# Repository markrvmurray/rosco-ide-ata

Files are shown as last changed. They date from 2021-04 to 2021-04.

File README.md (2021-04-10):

# IDE/ATA Interface for Rosco_68k

**(c) 2021 Mark R V Murray**

_v1.1 - first public release_

This is a minimalist PIO-only interface to PATA hard disk and
compatible devices.

It has received minimal testing, and is being released in the hope
that it may be useful to someone, somewhere.

The materials in this repository will, when assembled, give a board
that will map the IDE registers into the Rosco_68k's address space.

The addresses are mapped as follows:

| Address | Read | Write | Width in bits |
--- | --- | --- | ---
| 00F80040 | DATA | DATA | 16 |
| 00F80042 | Error | Features | 8 |
| 00F80044 | Sector Count | Sector Count | 8 |
| 00F80046 | Sector Number | Sector Number | 8 |
| 00F80048 | Cylinder Low | Cyllinder Low | 8 |
| 00F8004A | Cylinder High | Cylinder High | 8 |
| 00F8004C | Device and Head | Device and Head | 8 |
| 00F8004E | Status | Command | 8 |
| 00F80050 | (Not used) | | |
| 00F80052 | (Not used) | | |
| 00F80054 | (Not used) | | |
| 00F80056 | (Not used) | | |
| 00F80058 | (Not used) | | |
| 00F8005A | (Not used) | | |
| 00F8005C | Alternate Status | Device Control | 8 |
| 00F8005E | (Not used) | | |

The above memory locations base address may be changed by changing
the U1 image.  This is written in CUPL, and you will need a programmer
capable of programming GAL16V8s or the equivalent.

The supplied GAL images and jumper setting defaults will give the
IDE device IPL3. To change this, the three IPL jumpers on the board
will need to be changed; IPL0 and IPL1 can be cut, and all three
can be (re-)bridged with a solder blob if necessary.

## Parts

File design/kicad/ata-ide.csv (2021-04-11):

Ref | Value | Footprint | Datasheet | Manufacturer | Vendor
C1 | 100n | Capacitors_THT:C_Rect_L4.0mm_W2.5mm_P2.50mm | ~
C2 | 100n | Capacitors_THT:C_Rect_L4.0mm_W2.5mm_P2.50mm | ~
C3 | 100n | Capacitors_THT:C_Rect_L4.0mm_W2.5mm_P2.50mm | ~
C4 | 100n | Capacitors_THT:C_Rect_L4.0mm_W2.5mm_P2.50mm | ~
C5 | 100n | Capacitors_THT:C_Rect_L4.0mm_W2.5mm_P2.50mm | ~
C6 | 1u | Capacitors_THT:C_Rect_L7.0mm_W4.5mm_P5.00mm | ~
C7 | 10u | Capacitors_THT:CP_Radial_D8.0mm_P2.50mm | ~
C8 | 100u | Capacitors_THT:CP_Radial_D8.0mm_P2.50mm | ~
C9 | 4u7 | Capacitors_THT:C_Rect_L7.0mm_W4.5mm_P5.00mm | ~
D1 | LED | LEDs:LED_D5.0mm | http://www.farnell.com/datasheets/1811043.pdf |  | uk.farnell.com 2314284
J1 | Conn_02x32_Odd_Even | Connector_PinHeader_2.54mm:PinHeader_2x32_P2.54mm_Vertical | https://www.we-online.de/katalog/datasheet/613064243121.pdf |  | uk.farnell.com 2984322
J2 | Conn_02x20_Odd_Even | Pin_Headers:Pin_Header_Straight_2x20_Pitch2.54mm | http://www.farnell.com/datasheets/2012759.pdf |  | uk.farnell.com 1106737
J3 | Conn_02x22_Odd_Even | Pin_Headers:Pin_Header_Straight_2x22_Pitch2.00mm | http://www.farnell.com/datasheets/2701933.pdf |  | uk.farnell.com 1756945
JP1 | Pin 20 5V Supply | Pin_Headers:Pin_Header_Straight_1x02_Pitch2.54mm | ~
JP2 | SolderJumper_2_Bridged | Jumper:SolderJumper-2_P1.3mm_Bridged_Pad1.0x1.5mm | ~
JP3 | SolderJumper_2_Bridged | Jumper:SolderJumper-2_P1.3mm_Bridged_Pad1.0x1.5mm | ~
JP4 | SolderJumper_2_Bridged | Jumper:SolderJumper-2_P1.3mm_Bridged_Pad1.0x1.5mm | ~
JP5 | SolderJumper_2_Open | Jumper:SolderJumper-2_P1.3mm_Open_Pad1.0x1.5mm | ~
Q1 | 2N2907 | Package_TO_SOT_THT:TO-18-3 | http://www.farnell.com/datasheets/2869790.pdf |  | uk.farnell.com 9206892
R1 | 10k | Resistors_THT:R_Axial_DIN0207_L6.3mm_D2.5mm_P10.16mm_Horizontal | ~
R2 | 4k7 | Resistors_THT:R_Axial_DIN0207_L6.3mm_D2.5mm_P10.16mm_Horizontal | ~
R3 | 10k | Resistors_THT:R_Axial_DIN0207_L6.3mm_D2.5mm_P10.16mm_Horizontal | ~
R4 | 330 | Resistors_THT:R_Axial_DIN0207_L6.3mm_D2.5mm_P10.16mm_Horizontal | ~
R5 | 10k | Resistors_THT:R_Axial_DIN0207_L6.3mm_D2.5mm_P10.16mm_Horizontal | ~
U1 | 16V8 | Housings_DIP:DIP-20_W7.62mm_Socket_LongPads | http://www.farnell.com/datasheets/30132.pdf |  | uk.farnell.com 1551768
U2 | ATF750 | Housings_DIP:DIP-24_W7.62mm_Socket_LongPads | http://www.farnell.com/datasheets/1627044.pdf |  | uk.farnell.com 3580674
U3 | 74HCT241 | Housings_DIP:DIP-20_W7.62mm_Socket_LongPads | http://www.ti.com/lit/ds/symlink/sn74ls241.pdf |  | uk.farnell.com 3006090
U4 | 74HCT245 | Housings_DIP:DIP-20_W7.62mm_Socket_LongPads | http://www.ti.com/lit/gpn/sn74HC245 |  | uk.farnell.com 3119519
U5 | 74HCT245 | Housings_DIP:DIP-20_W7.62mm_Socket_LongPads | http://www.ti.com/lit/gpn/sn74HC245 |  | uk.farnell.com 3119519

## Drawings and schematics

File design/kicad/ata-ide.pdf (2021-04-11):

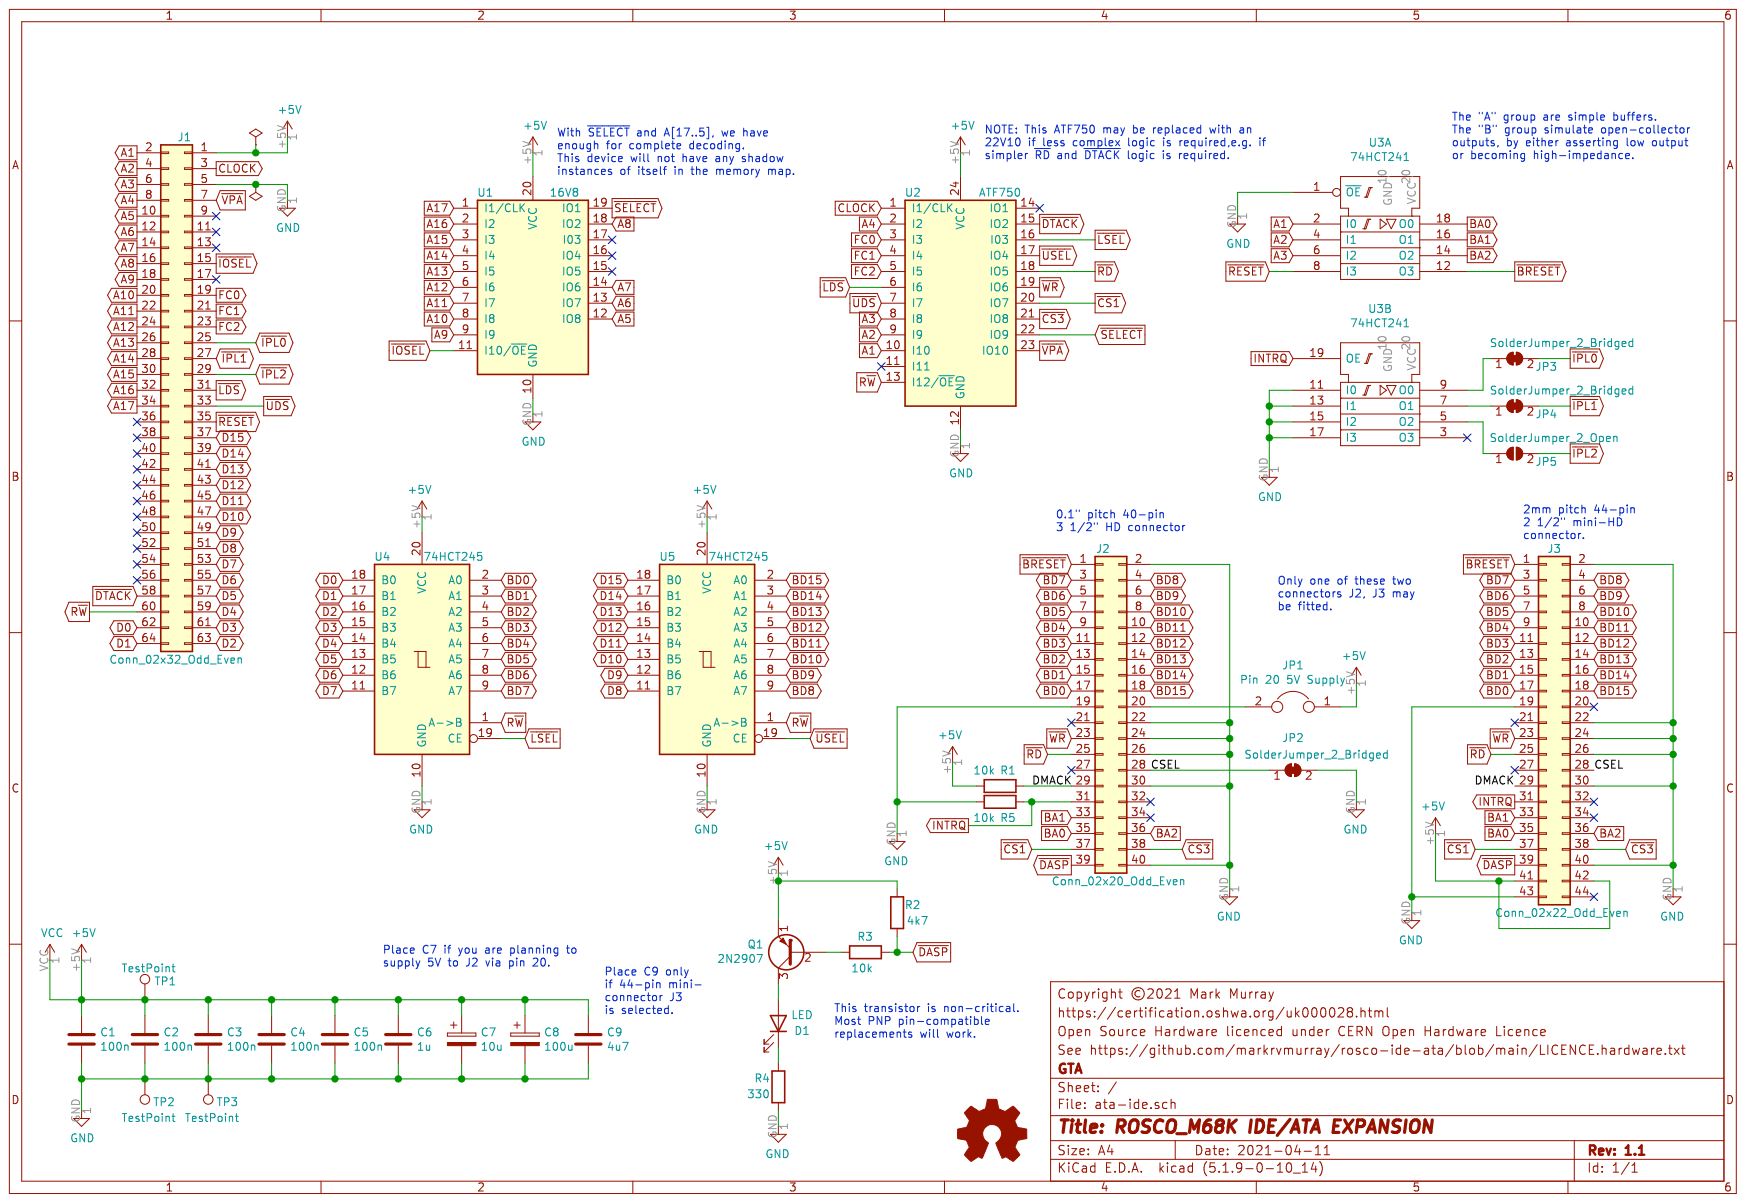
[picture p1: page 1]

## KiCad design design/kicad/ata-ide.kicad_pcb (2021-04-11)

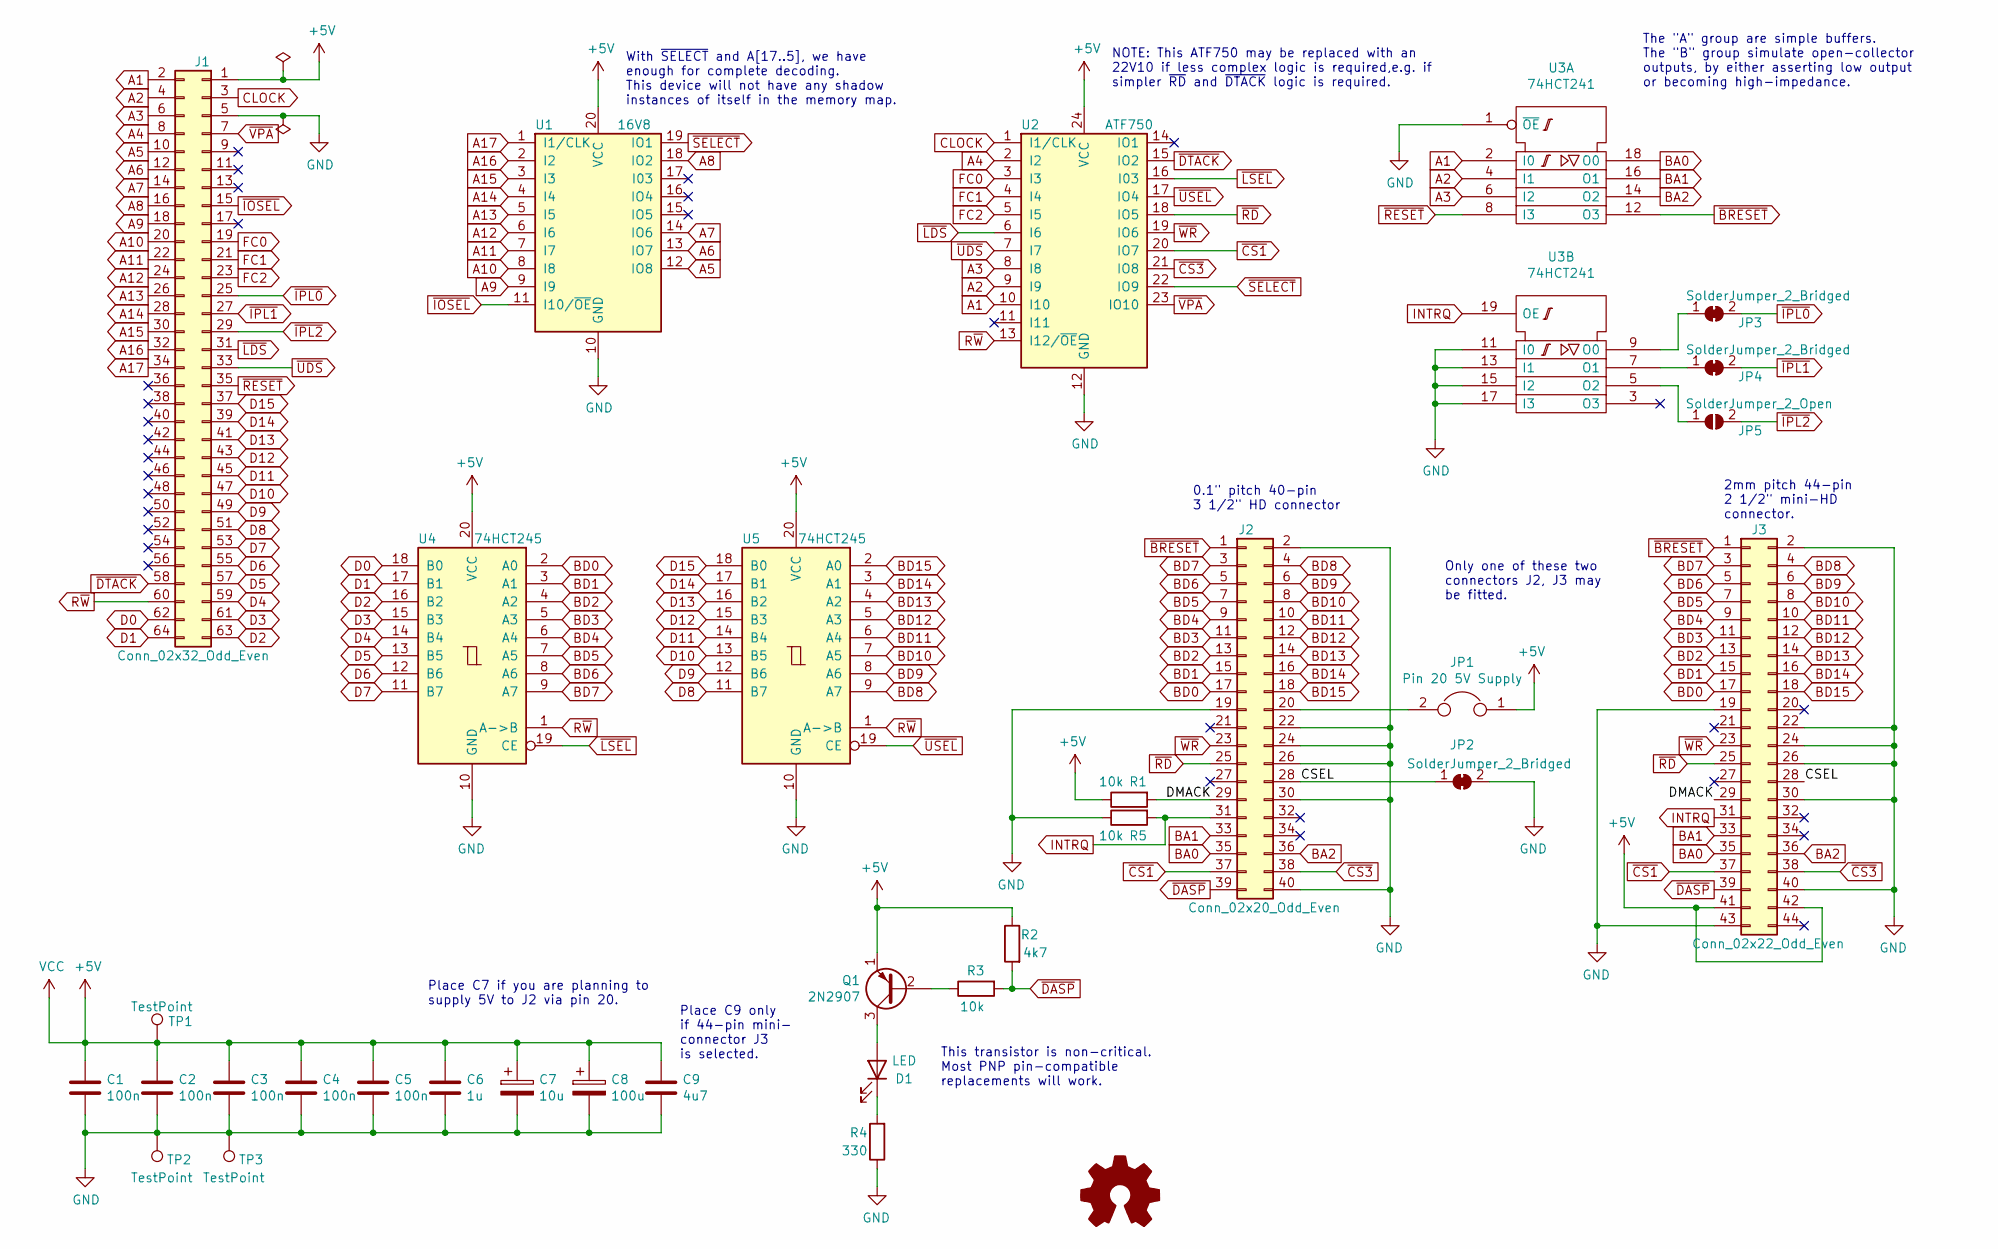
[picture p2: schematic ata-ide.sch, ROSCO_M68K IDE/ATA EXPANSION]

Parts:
C1, C2, C3, C4, C5: 100n; C_Rect_L4.0mm_W2.5mm_P2.50mm
C6: 1u; C_Rect_L7.0mm_W4.5mm_P5.00mm
C7: 10u; CP_Radial_D8.0mm_P2.50mm
C8: 100u; CP_Radial_D8.0mm_P2.50mm
C9: 4u7; C_Rect_L7.0mm_W4.5mm_P5.00mm
D1: LED; LED_D5.0mm
J1: Conn_02x32_Odd_Even; PinHeader_2x32_P2.54mm_Vertical
J2: Conn_02x20_Odd_Even; Pin_Header_Straight_2x20_Pitch2.54mm
J3: Conn_02x22_Odd_Even; Pin_Header_Straight_2x22_Pitch2.00mm
JP1: Pin 20 5V Supply; Pin_Header_Straight_1x02_Pitch2.54mm
JP2, JP3, JP4: SolderJumper_2_Bridged; SolderJumper-2_P1.3mm_Bridged_Pad1.0x1.5mm
JP5: SolderJumper_2_Open; SolderJumper-2_P1.3mm_Open_Pad1.0x1.5mm
Q1: 2N2907; TO-18-3
R1, R3, R5: 10k; R_Axial_DIN0207_L6.3mm_D2.5mm_P10.16mm_Horizontal
R2: 4k7; R_Axial_DIN0207_L6.3mm_D2.5mm_P10.16mm_Horizontal
R4: 330; R_Axial_DIN0207_L6.3mm_D2.5mm_P10.16mm_Horizontal
TP1, TP2, TP3: TestPoint; Measurement_Point_Round-TH_Big
U1: 16V8; DIP-20_W7.62mm_Socket_LongPads
U2: ATF750; DIP-24_W7.62mm_Socket_LongPads
U3: 74HCT241; DIP-20_W7.62mm_Socket_LongPads
U4, U5: 74HCT245; DIP-20_W7.62mm_Socket_LongPads

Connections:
/CSEL: J2.28, J3.28, JP2.1 (A)
/DMACK: J2.29, J3.29, R1.2
A1: J1.2, U2.10 (I10), U3.2 (I0)
A2: J1.4, U2.9 (I9), U3.4 (I1)
A3: J1.6, U2.8 (I8), U3.6 (I2)
A4: J1.8, U2.2 (I2)
A5: J1.10, U1.12 (IO8)
A6: J1.12, U1.13 (IO7)
A7: J1.14, U1.14 (IO6)
A8: J1.16, U1.18 (IO2)
A9: J1.18, U1.9 (I9)
A10: J1.20, U1.8 (I8)
A11: J1.22, U1.7 (I7)
A12: J1.24, U1.6 (I6)
A13: J1.26, U1.5 (I5)
A14: J1.28, U1.4 (I4)
A15: J1.30, U1.3 (I3)
A16: J1.32, U1.2 (I2)
A17: J1.34, U1.1 (I1/CLK)
BA0: J2.35, J3.35, U3.18 (O0)
BA1: J2.33, J3.33, U3.16 (O1)
BA2: J2.36, J3.36, U3.14 (O2)
BD0: J2.17, J3.17, U4.2 (A0)
BD1: J2.15, J3.15, U4.3 (A1)
BD2: J2.13, J3.13, U4.4 (A2)
BD3: J2.11, J3.11, U4.5 (A3)
BD4: J2.9, J3.9, U4.6 (A4)
BD5: J2.7, J3.7, U4.7 (A5)
BD6: J2.5, J3.5, U4.8 (A6)
BD7: J2.3, J3.3, U4.9 (A7)
BD8: J2.4, J3.4, U5.9 (A7)
BD9: J2.6, J3.6, U5.8 (A6)
BD10: J2.8, J3.8, U5.7 (A5)
BD11: J2.10, J3.10, U5.6 (A4)
BD12: J2.12, J3.12, U5.5 (A3)
BD13: J2.14, J3.14, U5.4 (A2)
BD14: J2.16, J3.16, U5.3 (A1)
BD15: J2.18, J3.18, U5.2 (A0)
CLOCK: J1.3, U2.1 (I1/CLK)
D0: J1.62, U4.18 (B0)
D1: J1.64, U4.17 (B1)
D2: J1.63, U4.16 (B2)
D3: J1.61, U4.15 (B3)
D4: J1.59, U4.14 (B4)
D5: J1.57, U4.13 (B5)
D6: J1.55, U4.12 (B6)
D7: J1.53, U4.11 (B7)
D8: J1.51, U5.11 (B7)
D9: J1.49, U5.12 (B6)
D10: J1.47, U5.13 (B5)
D11: J1.45, U5.14 (B4)
D12: J1.43, U5.15 (B3)
D13: J1.41, U5.16 (B2)
D14: J1.39, U5.17 (B1)
D15: J1.37, U5.18 (B0)
FC0: J1.19, U2.3 (I3)
FC1: J1.21, U2.4 (I4)
FC2: J1.23, U2.5 (I5)
INTRQ: J2.31, J3.31, R5.2, U3.19 (OE)
unnamed: D1.1 (K), R4.2
unnamed: D1.2 (A), Q1.3 (C)
unnamed: J2.20, JP1.2
unnamed: JP3.1 (A), U3.9 (O0)
unnamed: JP4.1 (A), U3.7 (O1)
unnamed: JP5.1 (A), U3.5 (O2)
unnamed: Q1.2 (B), R3.1
R~W~: J1.60, U2.13 (I12/~OE~), U4.1 (A->B), U5.1 (A->B)
~BRESET~: J2.1, J3.1, U3.12 (O3)
~CS1~: J2.37, J3.37, U2.20 (IO7)
~CS3~: J2.38, J3.38, U2.21 (IO8)
~DASP~: J2.39, J3.39, R2.2, R3.2
~DTACK~: J1.58, U2.15 (IO2)
~IOSEL~: J1.15, U1.11 (I10/~OE~)
~IPL0~: J1.25, JP3.2 (B)
~IPL1~: J1.27, JP4.2 (B)
~IPL2~: J1.29, JP5.2 (B)
~LDS~: J1.31, U2.6 (I6)
~LSEL~: U2.16 (I03), U4.19 (CE)
~RD~: J2.25, J3.25, U2.18 (IO5)
~RESET~: J1.35, U3.8 (I3)
~SELECT~: U1.19 (IO1), U2.22 (IO9)
~UDS~: J1.33, U2.7 (I7)
~USEL~: U2.17 (IO4), U5.19 (CE)
~VPA~: J1.7, U2.23 (IO10)
~WR~: J2.23, J3.23, U2.19 (IO6)

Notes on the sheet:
NOTE: This ATF750 may be replaced with an 22V10 if less complex logic is required,e.g. if simpler ~RD~ and ~DTACK~ logic is required.
The "A" group are simple buffers. The "B" group simulate open-collector outputs, by either asserting low output or becoming high-impedance.
With ~SELECT~ and A[17..5], we have enough for complete decoding. This device will not have any shadow instances of itself in the memory map.
This transistor is non-critical. Most PNP pin-compatible replacements will work.
Only one of these two connectors J2, J3 may be fitted.
Place C9 only if 44-pin mini- connector J3 is selected.
Place C7 if you are planning to supply 5V to J2 via pin 20.
0.1" pitch 40-pin 3 1/2" HD connector
2mm pitch 44-pin 2 1/2" mini-HD connector.

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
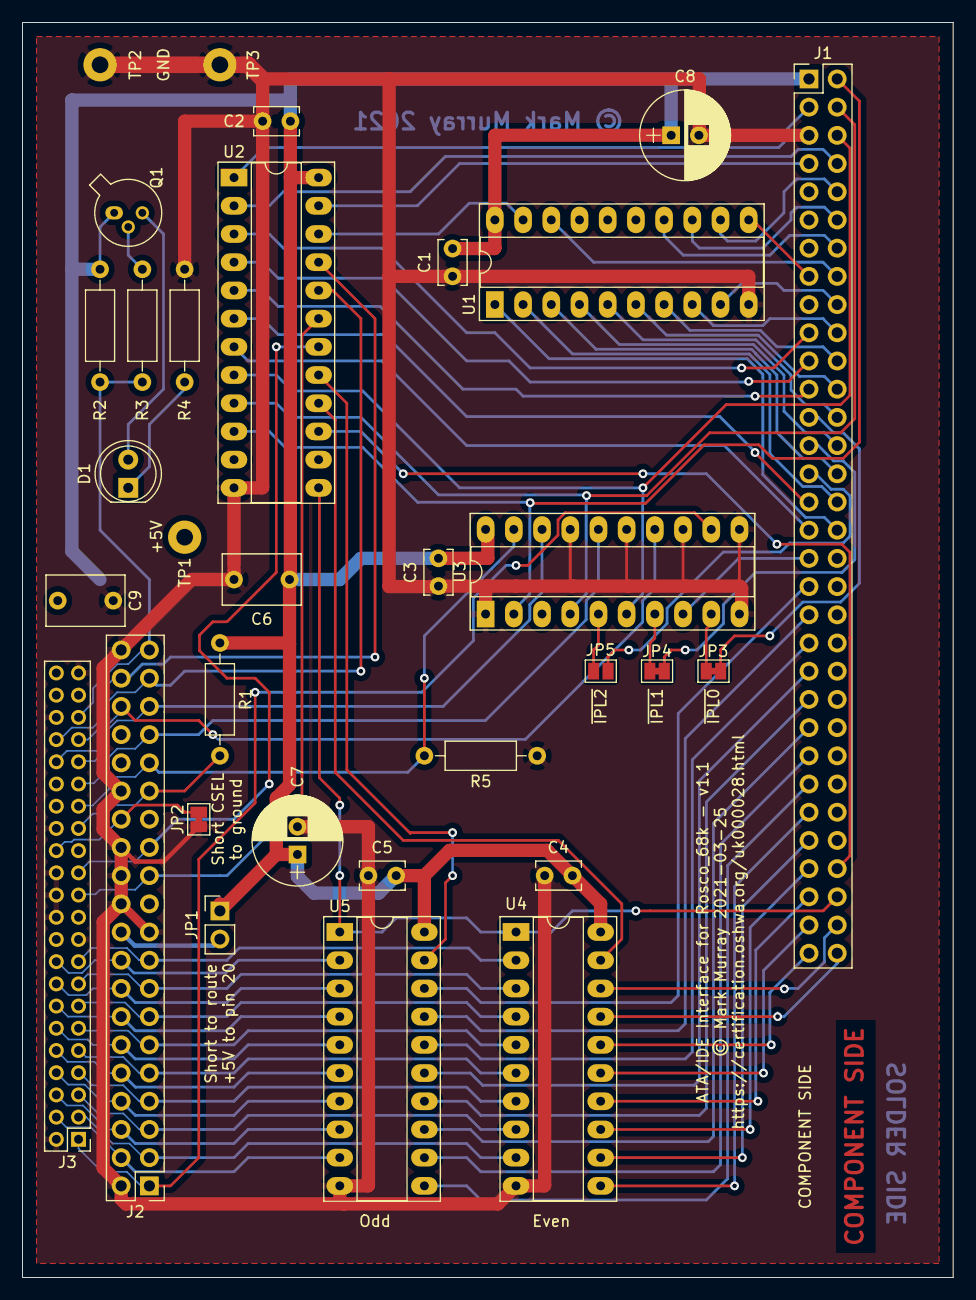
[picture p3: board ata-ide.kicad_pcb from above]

Board: 2 copper layers, 83.8 x 113.0 mm, 32 parts (0 on the bottom side), 87 nets.

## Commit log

2021-03-21 Initial snapshot of v1.0
    [ata-ide.csv, ata-ide.dsn, ata-ide.kicad_pcb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]
2021-03-28 Update for version 1.1.
    [ata-ide.kicad_pcb, ata-ide.sch]
2021-03-28 Correct address of device.
2021-03-28 Update to PDF of 1.1 schematic.
2021-04-05 Catch up rest of materials to 1.1.
    [ata-ide.csv]
2021-04-10 PCB v1.1 RC1
    [ata-ide.csv, ata-ide.kicad_pcb, ata-ide.sch]
2021-04-11 Add some tweeks to make things easier for builders.
    [ata-ide.csv, ata-ide.sch]
2021-04-11 Add some comments and correct dates.
    [ata-ide.kicad_pcb, ata-ide.sch]

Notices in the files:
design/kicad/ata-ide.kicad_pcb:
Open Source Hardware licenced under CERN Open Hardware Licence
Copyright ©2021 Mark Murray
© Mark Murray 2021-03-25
